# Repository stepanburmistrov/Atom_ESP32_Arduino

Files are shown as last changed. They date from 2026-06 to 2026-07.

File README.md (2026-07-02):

# RobotX UART Wi-Fi Robot

Готовый репозиторий для учебного робота RobotX с двумя режимами управления:

1. **Отладка с компьютера по USB/UART** — Python-пульт отправляет команды прямо в Arduino Nano.
2. **Работа через Wi-Fi модуль ESP32-C3** — телефон/планшет открывает веб-пульт, ESP32 пересылает команды в Arduino Nano по UART.

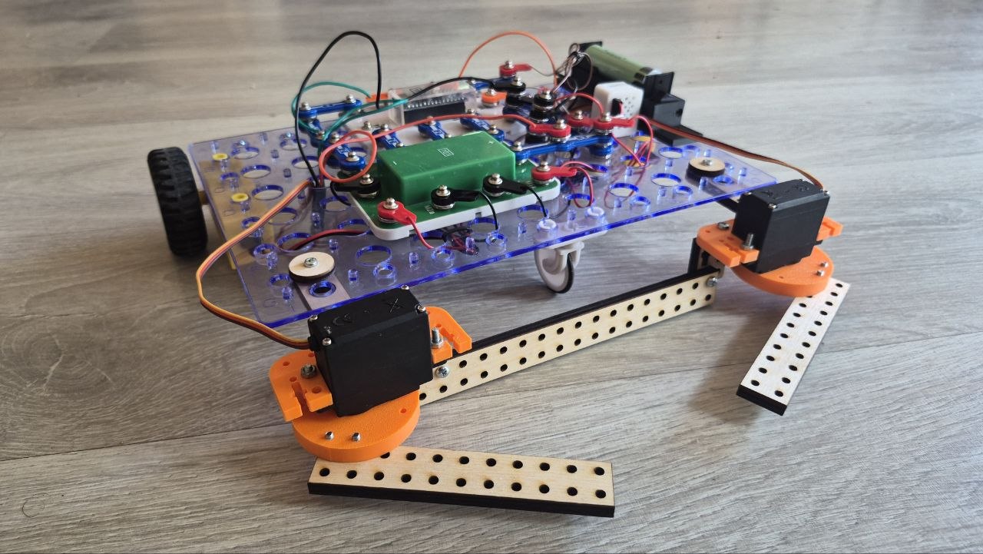
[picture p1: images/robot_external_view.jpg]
Внешний вид робота


## Быстрый старт

### Вариант 1. Отладка с компьютера без ESP32

1. Прошейте Arduino Nano скетчем из папки `arduino/RobotX_Nano_UART_Control/`.
2. Установите Python-зависимость:

```bash
pip install -r pc_control/requirements.txt
```

3. Запустите пульт:

```bash
python pc_control/robotx_uart_control.py
```

4. Выберите COM-порт Arduino Nano, скорость `9600`, нажмите **Подключиться**.

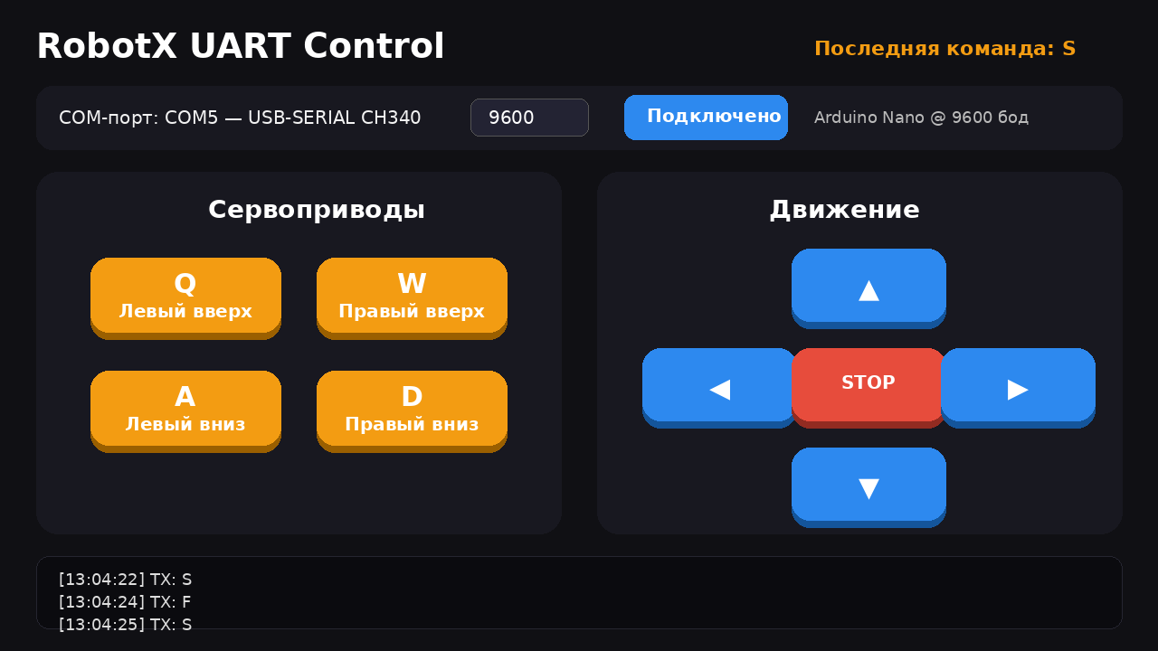
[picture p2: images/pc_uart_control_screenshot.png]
Python UART пульт


### Вариант 2. Управление через ESP32-C3 Wi-Fi

1. Прошейте ESP32-C3 скетчем из папки `esp32_wifi/RobotX_ESP32C3_WiFi_Joystick/`.
2. В Arduino IDE для ESP32-C3 включите: `Tools -> USB CDC On Boot -> Enabled`.
3. Подключите ESP32-C3 к Arduino Nano:

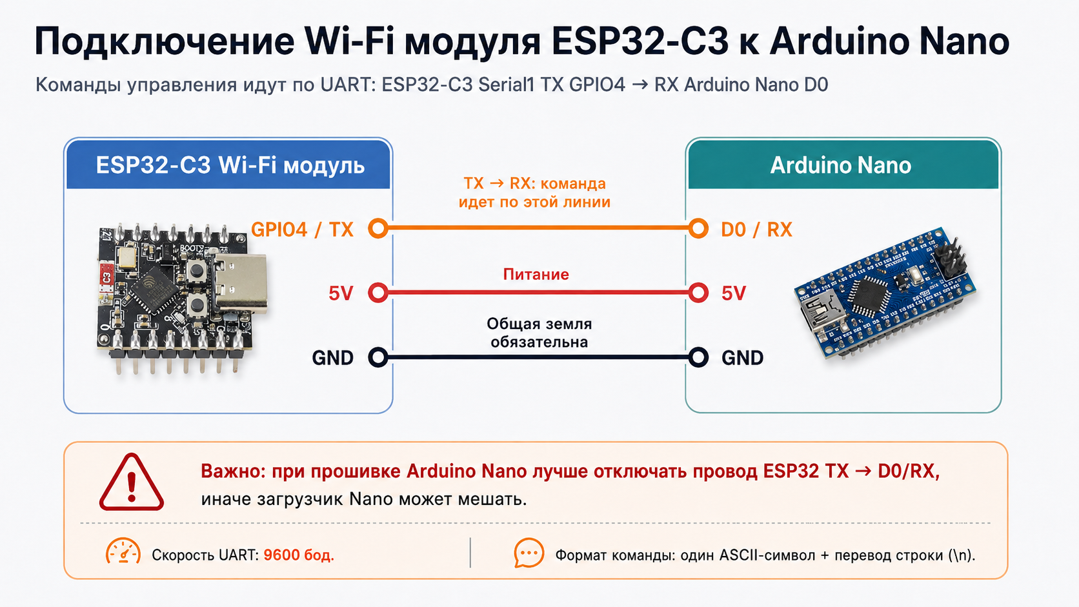
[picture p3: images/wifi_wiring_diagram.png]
Подключение проводов


4. Подключитесь телефоном к Wi-Fi сети ESP32.
5. Откройте в браузере адрес `http://192.168.4.1`.

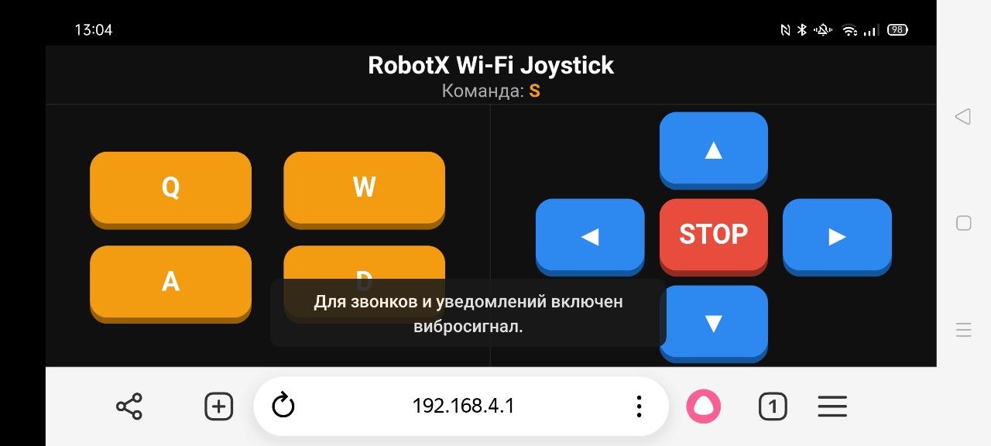
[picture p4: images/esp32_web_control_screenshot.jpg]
ESP32 веб-пульт


## Структура репозитория

```text
RobotX_UART_WiFi_Robot/
├── README.md
├── arduino/
│   ├── RobotX_Nano_UART_Control/
│   │   └── RobotX_Nano_UART_Control.ino
│   └── libraries/
│       └── ServoTimer2-master.zip
├── esp32_wifi/
│   └── RobotX_ESP32C3_WiFi_Joystick/
│       └── RobotX_ESP32C3_WiFi_Joystick.ino
├── pc_control/
│   ├── robotx_uart_control.py
│   └── requirements.txt
├── docs/
│   ├── arduino_project.md
│   ├── wifi_module.md
│   ├── uart_protocol.md
│   └── debug_pc_control.md
├── configs/
│   └── atom_network_presets.txt
├── stl/
│   └── *.stl
└── images/
```

## STL детали для 3D-печати

В папке `stl/` лежат детали для печати:

1. корпус для ESP32-C3;
2. держатели сервоприводов;
3. переходные детали для конструктора «Знаток».

## UART-протокол

Все управляющие команды — это один ASCII-символ и перевод строки `
`.

| Команда | Назначение |
|---|---|
| `F` | ехать вперёд |
| `B` | ехать назад |
| `L` | поворот влево |
| `R` | поворот вправо |
| `S` | стоп моторов |
| `Q` / `q` | левая серва вверх / остановить движение левой сервы вверх |
| `A` / `a` | левая серва вниз / остановить движение левой сервы вниз |
| `W` / `w` | правая серва вверх / остановить движение правой сервы вверх |
| `D` / `d` | правая серва вниз / остановить движение правой сервы вниз |

Подробнее: [`docs/uart_protocol.md`](docs/uart_protocol.md)

## Фотографии проекта

### Внешний вид робота

Внешний вид робота

### Используемые компоненты

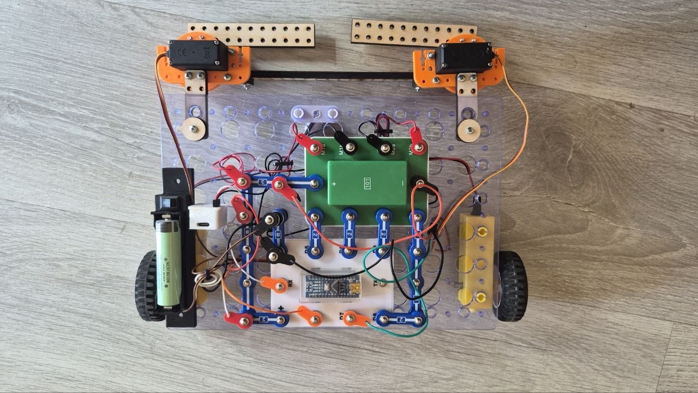
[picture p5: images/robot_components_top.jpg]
Компоненты робота


### Wi-Fi модуль

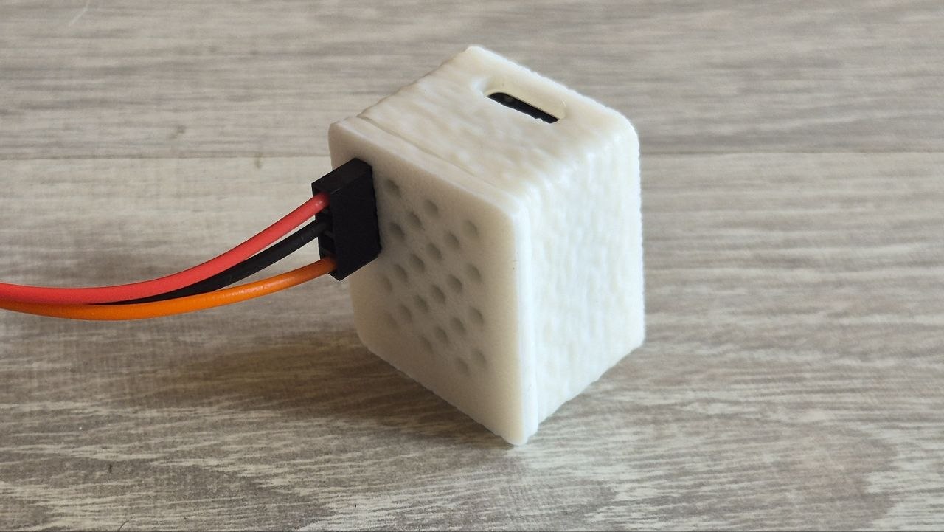
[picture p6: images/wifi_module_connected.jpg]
Wi-Fi модуль


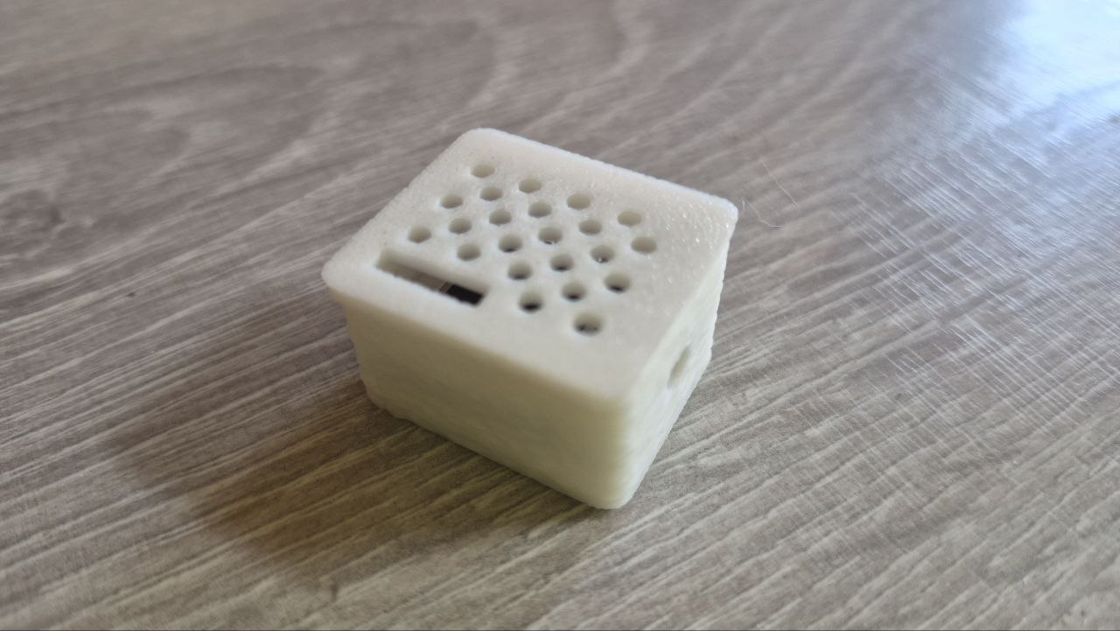
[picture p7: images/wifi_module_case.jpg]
Корпус Wi-Fi модуля


## Важные замечания

- Для работы Python-пульта нужен пакет `pyserial`.
- Для Arduino Nano нужна библиотека `ServoTimer2`; архив библиотеки лежит в `arduino/libraries/`.
- В Arduino-скетче при работе через ESP32 лучше поставить `#define DEBUG_SERIAL 0`, чтобы отладочные сообщения не мешали UART-линии.
- На Arduino Nano пины `D0/RX` и `D1/TX` используются также для загрузки скетча. Если прошивка не загружается, временно отключите провод от ESP32 TX к Nano RX.
- В ESP32-C3 для USB Serial обычно нужно включить `USB CDC On Boot: Enabled`.

## Документация

- [Arduino проект](docs/arduino_project.md)
- [Wi-Fi модуль ESP32-C3](docs/wifi_module.md)
- [UART-протокол](docs/uart_protocol.md)
- [Python-пульт для отладки](docs/debug_pc_control.md)

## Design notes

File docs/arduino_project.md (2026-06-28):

# Arduino Nano проект

Файл скетча: `arduino/RobotX_Nano_UART_Control/RobotX_Nano_UART_Control.ino`

## Что делает Arduino Nano

Arduino Nano является нижним уровнем управления роботом. Он принимает UART-команды и управляет:

- двумя моторами движения;
- двумя сервоприводами клешней/манипуляторов.

Команды могут приходить двумя способами:

1. напрямую с компьютера через USB и Python-пульт;
2. от ESP32-C3 Wi-Fi модуля через UART.

## Основные настройки в коде

### Отладка

```cpp
#define DEBUG_SERIAL 1
```

- `1` — Arduino печатает отладочные сообщения в Serial;
- `0` — отладка отключена.

При прямой отладке с компьютера можно оставить `1`.
При работе через ESP32 лучше поставить `0`, потому что Serial используется для приёма команд, а лишний текст может мешать анализу обмена.

### Скорость UART

```cpp
const int UART_BAUD = 9600;
```

Это скорость связи. Она должна совпадать во всех местах:

- Arduino Nano: `9600`;
- Python-пульт: `9600`;
- ESP32-C3 `Serial1`: `9600`.

### Пины моторов

```cpp
const int LEFT_DIR_PIN  = 5;
const int LEFT_PWM_PIN  = 6;

const int RIGHT_DIR_PIN = 8;
const int RIGHT_PWM_PIN = 9;
```

Что менять:

- `LEFT_DIR_PIN` и `RIGHT_DIR_PIN` — пины направления;
- `LEFT_PWM_PIN` и `RIGHT_PWM_PIN` — пины скорости, должны поддерживать PWM.

### Скорость моторов

```cpp
int motorSpeed = 120;
```

Диапазон: `0...255`.

- меньше значение — робот едет медленнее;
- больше значение — робот едет быстрее;
- для отладки лучше начинать с `80...120`.

### Пины сервоприводов

```cpp
const int LEFT_SERVO_PIN  = A4;
const int RIGHT_SERVO_PIN = 7;
```

Если сервы подключены к другим пинам, менять нужно эти две строки.

### Начальные углы сервоприводов

```cpp
int leftServoAngle  = 90;
int rightServoAngle = 90;
```

Это стартовое положение серв. Если при включении клешни стоят неудобно, можно подобрать другие значения.

### Ограничения углов

```cpp
const int SERVO_MIN_ANGLE = 0;
const int SERVO_MAX_ANGLE = 180;
```

Если механизм упирается раньше полного хода, лучше ограничить диапазон, например:

```cpp
const int SERVO_MIN_ANGLE = 20;
const int SERVO_MAX_ANGLE = 160;
```

### Плавность движения серв

```cpp
const int SERVO_STEP = 1;
const unsigned long SERVO_INTERVAL = 5;
```

- `SERVO_STEP` — насколько градусов менять положение за один шаг;
- `SERVO_INTERVAL` — пауза между шагами в миллисекундах.

Меньше интервал и больше шаг — быстрее движение. Больше интервал и меньше шаг — плавнее движение.

### Отключение серв после отпускания кнопки

```cpp
const unsigned long SERVO_DETACH_DELAY = 200;
```

Через 200 мс после окончания движения серва отключается методом `detach()`.
Это снижает дрожание, писк и лишнее потребление тока.

## Зачем нужна библиотека ServoTimer2

В обычных проектах часто используют стандартную библиотеку:

```cpp
#include <Servo.h>
```

Но на Arduino Nano стандартная `Servo` использует таймер `Timer1`. Из-за этого перестаёт нормально работать PWM на пинах `9` и `10`.

В этом роботе правый мотор использует PWM на пине `9`:

```cpp
const int RIGHT_PWM_PIN = 9;
```

Поэтому стандартная `Servo` конфликтовала бы с управлением мотором.

Решение — использовать:

```cpp
#include <ServoTimer2.h>
```

`ServoTimer2` использует другой таймер и не ломает PWM на 9 пине. Именно поэтому в коде сервоприводы управляются через `ServoTimer2`, а не через стандартную `Servo`.

## Как установить ServoTimer2

1. Возьмите архив `arduino/libraries/ServoTimer2-master.zip`.
2. В Arduino IDE откройте `Sketch -> Include Library -> Add .ZIP Library...`.
3. Выберите этот архив.
4. После установки перезапустите Arduino IDE, если библиотека не подтянулась сразу.

## Логика движения

```cpp
void forward() {
  setLeftMotor(motorSpeed);
  setRightMotor(motorSpeed);
}
```

```cpp
void back() {
  setLeftMotor(-motorSpeed);
  setRightMotor(-motorSpeed);
}
```

```cpp
void turnLeft() {
  setLeftMotor(-motorSpeed);
  setRightMotor(motorSpeed);
}
```

```cpp
void turnRight() {
  setLeftMotor(motorSpeed);
  setRightMotor(-motorSpeed);
}
```

Если робот едет назад вместо вперёд, можно поменять знак у соответствующего мотора или поменять логику в `setLeftMotor()` / `setRightMotor()`.

## Частые проблемы

### Робот не реагирует на команды

Проверьте:

- скорость Serial = `9600`;
- выбран правильный COM-порт;
- команды отправляются с переводом строки `
`;
- при работе через ESP32 есть общий GND между ESP32 и Nano;
- ESP32 TX GPIO4 подключен к Nano RX D0.

### Скетч не загружается в Arduino Nano

Если к пину `D0/RX` подключен ESP32, он может мешать загрузчику Nano. На время прошивки отключите провод `ESP32 TX -> Nano RX`.

### Мотор на 9 пине перестал работать после добавления серв

Нужно использовать `ServoTimer2`, а не стандартную `Servo`. Стандартная библиотека Servo конфликтует с PWM на 9 пине.

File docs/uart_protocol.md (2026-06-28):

# UART-протокол RobotX

## Назначение

UART-протокол нужен, чтобы разные пульты управления могли одинаково управлять Arduino Nano:

- Python-пульт на компьютере отправляет команды через USB Serial Arduino Nano;
- ESP32-C3 получает команды с веб-страницы и пересылает их в Arduino Nano через `Serial1`;
- Arduino Nano не знает, кто именно отправил команду, он просто принимает символы по UART.

## Параметры UART

| Параметр | Значение |
|---|---|
| Скорость | `9600` бод |
| Формат | `SERIAL_8N1` |
| Окончание команды | `
` |
| Кодировка | ASCII |
| Длина полезной команды | 1 символ |

Пример фактической строки:

```text
F

```

## Команды движения

| Команда | Действие Arduino Nano |
|---|---|
| `F` | оба мотора вперёд |
| `B` | оба мотора назад |
| `L` | левый мотор назад, правый вперёд |
| `R` | левый мотор вперёд, правый назад |
| `S` | оба мотора остановлены |

В Python-пульте и веб-пульте команды движения работают как **удерживаемые кнопки**: при нажатии отправляется `F/B/L/R`, при отпускании — `S`.

## Команды сервоприводов

| Команда | Действие |
|---|---|
| `Q` | начать движение левой сервы вверх |
| `q` | остановить движение левой сервы вверх |
| `A` | начать движение левой сервы вниз |
| `a` | остановить движение левой сервы вниз |
| `W` | начать движение правой сервы вверх |
| `w` | остановить движение правой сервы вверх |
| `D` | начать движение правой сервы вниз |
| `d` | остановить движение правой сервы вниз |

Правая серва установлена зеркально, поэтому внутри Arduino-скетча направления `W/D` специально инвертированы.

## Почему команды верхнего и нижнего регистра разные

Для сервоприводов верхний регистр означает **начать движение**, нижний регистр — **остановить соответствующее движение**.

Например:

```text
Q
  левая серва начала двигаться вверх
q
  левая серва остановилась
```

Это удобно для кнопок на экране и клавиатуре: кнопка нажата — серва едет, кнопка отпущена — серва остановилась.

## Проверка без робота

В Arduino IDE можно открыть Serial Monitor на `9600` бод и отправлять команды вручную:

```text
F
S
Q
q
A
a
```

Если включён `DEBUG_SERIAL`, Nano будет печатать диагностические сообщения. При работе с ESP32 лучше отключить отладку:

```cpp
#define DEBUG_SERIAL 0
```

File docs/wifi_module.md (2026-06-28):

# Wi-Fi модуль ESP32-C3

Файл скетча: `esp32_wifi/RobotX_ESP32C3_WiFi_Joystick/RobotX_ESP32C3_WiFi_Joystick.ino`

Wi-Fi модуль с проводами

## Назначение

ESP32-C3 работает как мост:

```text
Телефон / планшет / компьютер
        ↓ Wi-Fi + HTTP
ESP32-C3 WebServer
        ↓ UART Serial1, 9600 бод
Arduino Nano
        ↓
моторы и сервоприводы
```

ESP32 не управляет моторами напрямую. Он только показывает веб-страницу и пересылает команды в Arduino Nano.

## Подключение к Arduino Nano

Подключение проводов

| ESP32-C3 | Arduino Nano | Назначение |
|---|---|---|
| `GPIO4 / TX` | `D0 / RX` | команды от ESP32 к Nano |
| `GPIO5 / RX` | `D1 / TX` | необязательно, обратный канал пока не используется |
| `GND` | `GND` | общая земля, обязательно |

В коде ESP32:

```cpp
const int UART_TX_PIN = 4;
const int UART_RX_PIN = 5;
const int UART_BAUD   = 9600;
```

## Подключение по стандартной точке доступа

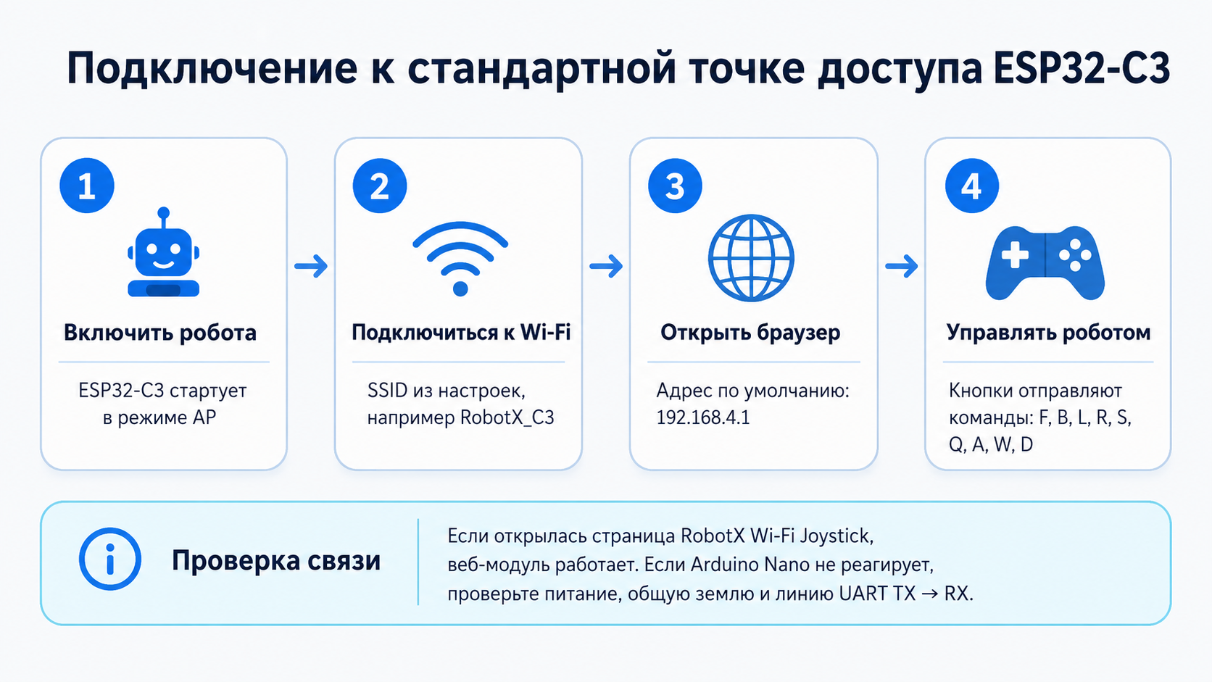
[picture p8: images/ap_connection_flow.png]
Подключение к AP


1. Включить робота.
2. Подключиться телефоном к Wi-Fi сети ESP32.
3. Открыть браузер.
4. Перейти на адрес:

```text
http://192.168.4.1
```

Откроется пульт:

Веб-пульт ESP32

## Веб-адреса

### Главная страница

```text
/
```

Открывает HTML-пульт управления.

### Отправка команды

```text
/cmd?c=F
```

Параметр `c` — команда. Примеры:

```text
/cmd?c=F  вперёд
/cmd?c=S  стоп
/cmd?c=Q  левая серва вверх
/cmd?c=q  остановить движение левой сервы вверх
```

### Информация о модуле

```text
/info
```

Возвращает текстовую информацию:

- режим Wi-Fi;
- имя AP;
- STA SSID;
- текущий IP;
- UART TX/RX;
- скорость UART.

## USB Serial для настройки

Настройка ESP32 выполняется через USB Serial на скорости `115200` бод.

Для ESP32-C3 в Arduino IDE обычно нужно включить:

```text
Tools -> USB CDC On Boot -> Enabled
```

После прошивки откройте Serial Monitor:

```text
115200 baud
Newline или Both NL & CR
```

## Команды настройки

### HELP

```text
HELP
```

Печатает список доступных команд.

### INFO

```text
INFO
```

Показывает текущие настройки:

- режим `AP` или `STA`;
- AP SSID и пароль;
- STA SSID и пароль;
- статический IP включён или нет;
- текущий IP.

### SETMODE AP

```text
SETMODE AP
```

Сохраняет режим точки доступа. После команды нужно выполнить:

```text
REBOOT
```

### SETMODE STA

```text
SETMODE STA
```

Сохраняет режим подключения к существующей Wi-Fi сети. После команды нужно задать сеть командой `SETSTA`, а затем выполнить `REBOOT`.

### SETAP

```text
SETAP Atom_BAL 55551111
```

Задаёт имя и пароль точки доступа ESP32.

Формат:

```text
SETAP <SSID> <PASSWORD>
```

Требования:

- пароль AP должен быть не короче 8 символов;
- SSID и пароль лучше писать без пробелов.

### SETSTA

```text
SETSTA MyWiFi mypassword
```

Задаёт сеть, к которой ESP32 будет подключаться в режиме `STA`.

Формат:

```text
SETSTA <SSID> <PASSWORD>
```

### SETDHCP

```text
SETDHCP
```

Отключает статический IP. В режиме `STA` адрес будет выдаваться роутером.

### SETSTATIC

```text
SETSTATIC 192.168.1.77 192.168.1.1 255.255.255.0 8.8.8.8
```

Формат:

```text
SETSTATIC <IP> <GATEWAY> <SUBNET> <DNS>
```

В репозиторной версии скетча статический IP не только сохраняется в NVS, но и применяется перед `WiFi.begin()` через `WiFi.config(...)`.

### REBOOT

```text
REBOOT
```

Перезагружает ESP32. Нужен после изменения режима или Wi-Fi настроек.

## Пример настройки точки доступа

```text
SETAP Atom_BAL 55551111
SETMODE AP
REBOOT
```

После перезагрузки подключиться к сети `Atom_BAL` с паролем `55551111` и открыть:

```text
http://192.168.4.1
```

## Пример настройки подключения к роутеру

```text
SETSTA MyWiFi mypassword
SETMODE STA
SETDHCP
REBOOT
```

После перезагрузки ESP32 подключится к роутеру. Текущий IP можно посмотреть командой `INFO` через USB Serial или в интерфейсе роутера.

## Что проверено в коде

- Веб-страница отправляет `/cmd?c=...`.
- Обработчик `/cmd` вызывает `sendToNano(cmd)`.
- `sendToNano()` отправляет команду в `Serial1` и добавляет `
`.
- `Serial1` настроен как `9600, SERIAL_8N1, RX=GPIO5, TX=GPIO4`.
- Настройки Wi-Fi сохраняются в `Preferences` / NVS.
- Для режима `STA` добавлено применение статического IP через `WiFi.config(...)`.

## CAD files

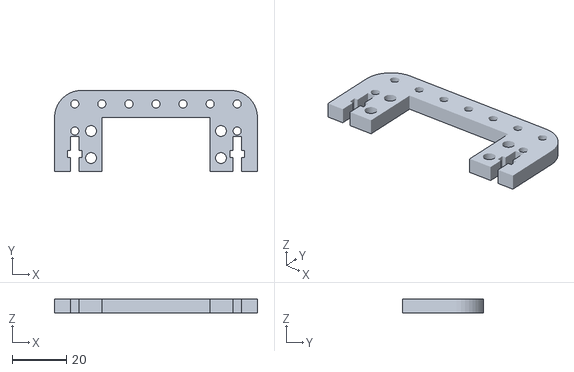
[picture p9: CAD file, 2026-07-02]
STL/Скоба крепления сервопривода.STL
75.0 x 30.0 x 5.00

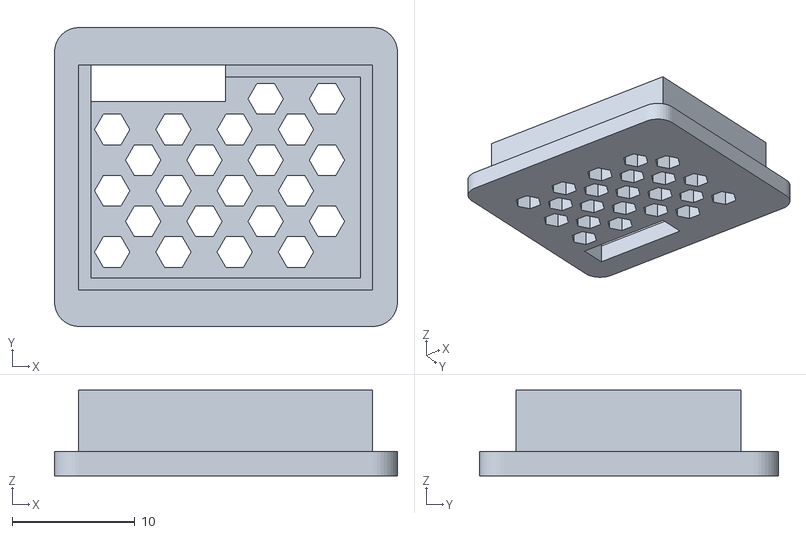
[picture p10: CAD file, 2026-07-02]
STL/Крышка корпуса ESP.STL
28.0 x 24.4 x 7.00

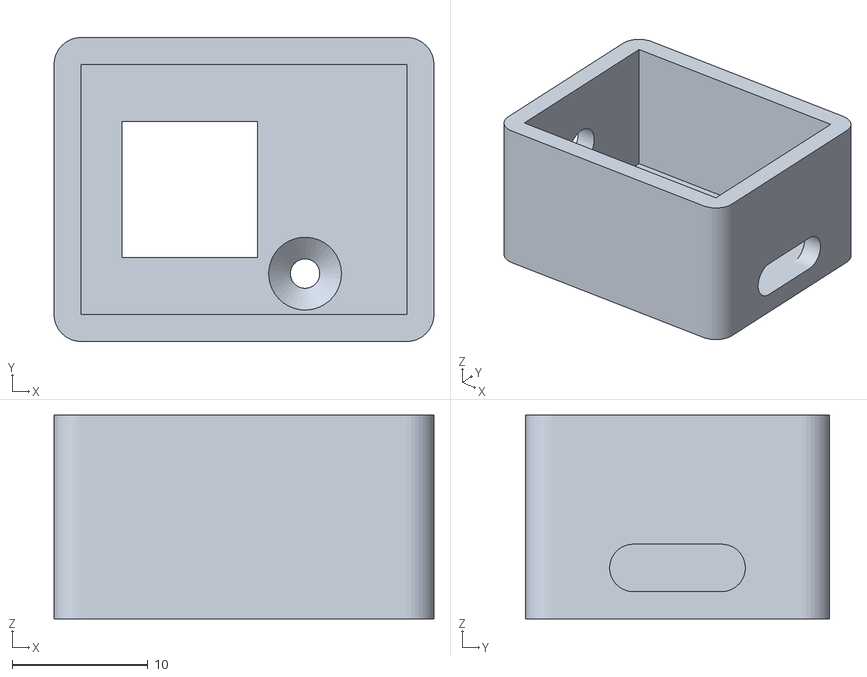
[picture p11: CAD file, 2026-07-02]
STL/Корпус ESP.STL
28.0 x 22.4 x 15.0

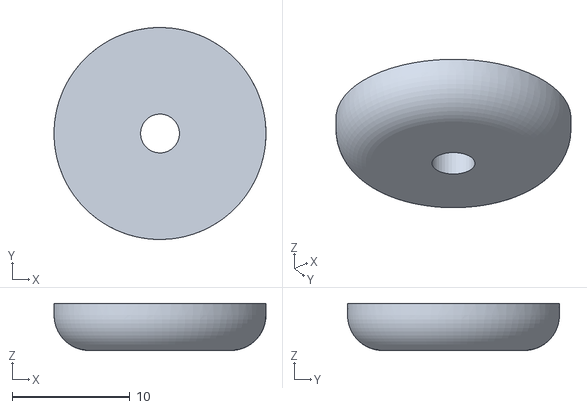
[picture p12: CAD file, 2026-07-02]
STL/Шайба.STL
18.0 x 18.0 x 4.00

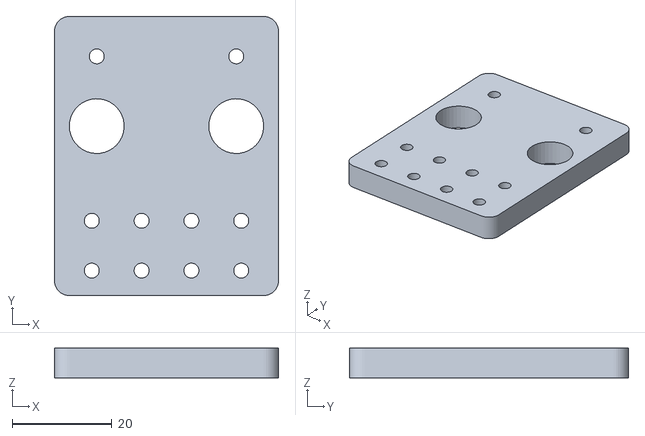
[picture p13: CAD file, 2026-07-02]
STL/Деталь 01.STL
45.0 x 56.0 x 6.00

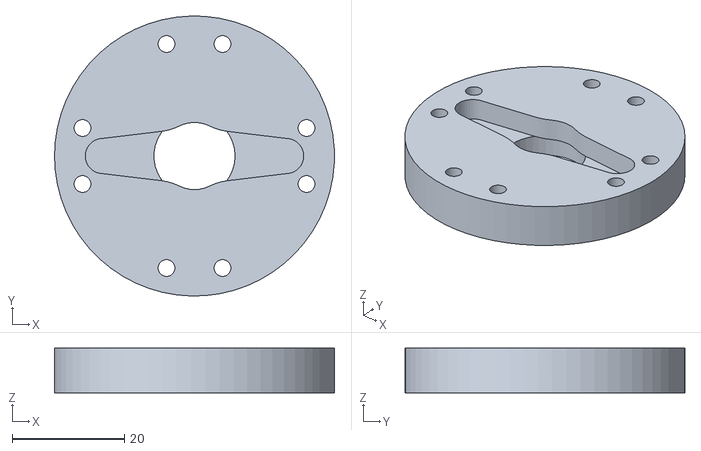
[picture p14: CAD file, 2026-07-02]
STL/КругПечать.STL
50.0 x 50.0 x 8.00

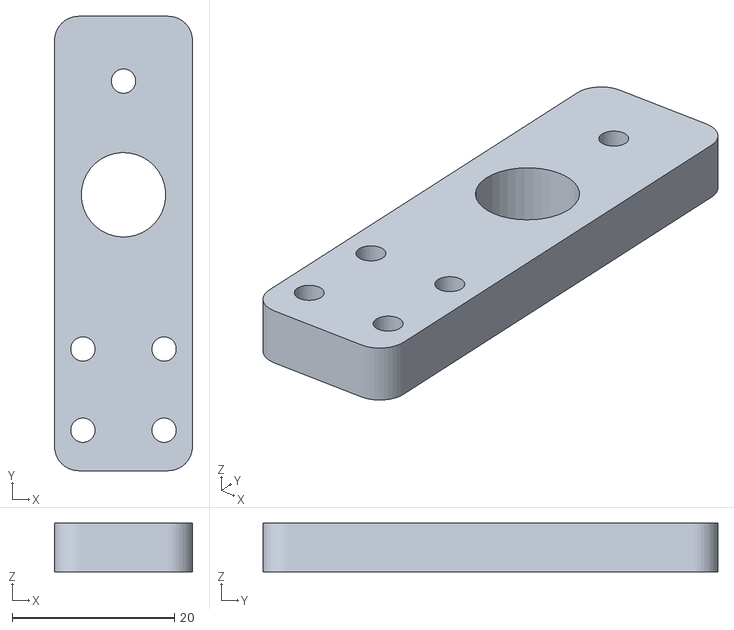
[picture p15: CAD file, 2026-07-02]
STL/Деталь 01-1.STL
17.0 x 56.0 x 6.00

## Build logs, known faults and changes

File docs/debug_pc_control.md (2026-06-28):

# Python-пульт для отладки с компьютера

Файл: `pc_control/robotx_uart_control.py`

Python UART пульт

## Зачем нужен

Этот пульт нужен, чтобы отлаживать Arduino Nano и механику робота **до подключения ESP32**.

Схема работы:

```text
Компьютер
  ↓ USB кабель
Arduino Nano
  ↓
моторы и сервоприводы
```

Python отправляет в Arduino Nano те же команды, которые позже будет отправлять ESP32.

## Установка

В папке репозитория выполнить:

```bash
pip install -r pc_control/requirements.txt
```

## Запуск

```bash
python pc_control/robotx_uart_control.py
```

## Управление мышью

Кнопки на экране работают как удерживаемые:

- нажали кнопку — команда отправилась;
- отпустили кнопку — отправилась команда остановки.

Для движения при отпускании отправляется `S`.
Для сервоприводов при отпускании отправляется соответствующая маленькая буква: `q`, `a`, `w`, `d`.

## Управление клавиатурой

| Клавиша | Команда |
|---|---|
| `↑` | `F` — вперёд |
| `↓` | `B` — назад |
| `←` | `L` — влево |
| `→` | `R` — вправо |
| `Space` | `S` — стоп |
| `Q` | `Q/q` — левая серва вверх / стоп |
| `A` | `A/a` — левая серва вниз / стоп |
| `W` | `W/w` — правая серва вверх / стоп |
| `D` | `D/d` — правая серва вниз / стоп |

Для моторов специально используются стрелки, чтобы не конфликтовать с командами сервоприводов `Q/W/A/D`.

## Настройки

По умолчанию скорость:

```text
9600 бод
```

Она должна совпадать с Arduino:

```cpp
const int UART_BAUD = 9600;
```

## Режим DEMO

Если COM-порт не подключён, кнопки всё равно будут писать команды в лог как `DEMO TX`. Это удобно, чтобы проверить интерфейс без робота.

## Частые проблемы

### COM-порт не появился

Проверьте:

- подключён ли USB кабель;
- установлен ли драйвер CH340/FTDI;
- не открыт ли этот порт в Arduino IDE Serial Monitor.

### Arduino перезагружается при подключении

Это нормально: многие платы Nano перезапускаются при открытии Serial-порта. В программе после подключения есть небольшая пауза, чтобы плата успела стартовать.

### Робот не реагирует

Проверьте:

- выбран правильный COM-порт;
- скорость 9600;
- Arduino прошит скетчем `RobotX_Nano_UART_Control.ino`;
- в Arduino IDE закрыт Serial Monitor, иначе порт может быть занят.

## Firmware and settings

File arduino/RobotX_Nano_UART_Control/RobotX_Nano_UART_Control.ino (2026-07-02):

/*
  RobotX Nano UART Control
  ------------------------
  Управляет двумя моторами и двумя сервоприводами по UART-командам.
  Команды приходят по Serial на скорости 9600 бод: от Python-пульта через USB
  или от ESP32-C3 Wi-Fi модуля через GPIO4 -> RX Arduino Nano.

  Подробнее: см. docs/arduino_project.md и docs/uart_protocol.md
*/

#include <ServoTimer2.h>

// =====================
// ОТЛАДКА
// 1 — включить отладку в Serial
// 0 — выключить отладку
// ВАЖНО: при работе с ESP32 лучше ставить 0,
// потому что команды тоже приходят в RX Serial.
// =====================

#define DEBUG_SERIAL 1

#if DEBUG_SERIAL
  #define DBG_BEGIN(x) Serial.begin(x)
  #define DBG_PRINT(x) Serial.print(x)
  #define DBG_PRINTLN(x) Serial.println(x)
#else
  #define DBG_BEGIN(x)
  #define DBG_PRINT(x)
  #define DBG_PRINTLN(x)
#endif

// =====================
// UART ОТ ESP32
// =====================

const int UART_BAUD = 9600;

// =====================
// МОТОРЫ
// =====================

const int LEFT_DIR_PIN  = 5;
const int LEFT_PWM_PIN  = 6;

const int RIGHT_DIR_PIN = 8;
const int RIGHT_PWM_PIN = 9;

int motorSpeed = 160;

// =====================
// СЕРВЫ
// =====================

ServoTimer2 leftServo;
ServoTimer2 rightServo;

const int LEFT_SERVO_PIN  = A4;
const int RIGHT_SERVO_PIN = 7;

int leftServoAngle  = 90;
int rightServoAngle = 90;

const int SERVO_MIN_ANGLE = 0;
const int SERVO_MAX_ANGLE = 180;

const int SERVO_STEP = 1;
const unsigned long SERVO_INTERVAL = 5;

// Через сколько мс после окончания движения отключать серву
const unsigned long SERVO_DETACH_DELAY = 200;

unsigned long lastServoTime = 0;

bool leftServoAttached = false;
bool rightServoAttached = false;

unsigned long leftServoLastActiveTime = 0;
unsigned long rightServoLastActiveTime = 0;

// =====================
// СОСТОЯНИЕ СЕРВО
// =====================

bool leftServoUp     = false;
bool leftServoDown   = false;
bool rightServoUp    = false;
bool rightServoDown  = false;

// =====================
// ОТЛАДОЧНЫЙ ТАЙМЕР
// =====================

#if DEBUG_SERIAL
unsigned long lastDebugTime = 0;
const unsigned long DEBUG_INTERVAL = 500;
#endif

// =====================
// СЕРВО TIMER2
// =====================

int angleToPulse(int angle) {
  angle = constrain(angle, 0, 180);
  return map(angle, 0, 180, 750, 2250);
}

void writeServoAngle(ServoTimer2 &s, int angle) {
  s.write(angleToPulse(angle));
}

void attachLeftServoIfNeeded() {
  if (!leftServoAttached) {
    leftServo.attach(LEFT_SERVO_PIN);
    leftServoAttached = true;

    // Сразу записываем текущий угол,
    // чтобы серва не дернулась в случайное положение
    writeServoAngle(leftServo, leftServoAngle);

    DBG_PRINTLN("LEFT SERVO ATTACH");
  }

  leftServoLastActiveTime = millis();
}

void attachRightServoIfNeeded() {
  if (!rightServoAttached) {
    rightServo.attach(RIGHT_SERVO_PIN);
    rightServoAttached = true;

    // Сразу записываем текущий угол,
    // чтобы серва не дернулась в случайное положение
    writeServoAngle(rightServo, rightServoAngle);

    DBG_PRINTLN("RIGHT SERVO ATTACH");
  }

  rightServoLastActiveTime = millis();
}

void detachServosIfNeeded() {
  unsigned long now = millis();

  bool leftMoving = leftServoUp || leftServoDown;
  bool rightMoving = rightServoUp || rightServoDown;

  if (leftServoAttached && !leftMoving) {
    if (now - leftServoLastActiveTime >= SERVO_DETACH_DELAY) {
      leftServo.detach();
      leftServoAttached = false;

      DBG_PRINTLN("LEFT SERVO DETACH");
    }
  }

  if (rightServoAttached && !rightMoving) {
    if (now - rightServoLastActiveTime >= SERVO_DETACH_DELAY) {
      rightServo.detach();
      rightServoAttached = false;

      DBG_PRINTLN("RIGHT SERVO DETACH");
    }
  }
}

// =====================
// SETUP
// =====================

void setup() {
  Serial.begin(UART_BAUD);
  Serial.setTimeout(10);

  DBG_PRINTLN("================================");
  DBG_PRINTLN("RobotX Arduino Nano UART control");
  DBG_PRINTLN("RX commands from ESP32");
  DBG_PRINTLN("================================");

  pinMode(LEFT_DIR_PIN, OUTPUT);
  pinMode(LEFT_PWM_PIN, OUTPUT);

  pinMode(RIGHT_DIR_PIN, OUTPUT);
  pinMode(RIGHT_PWM_PIN, OUTPUT);

  // ВАЖНО:
  // Сервы НЕ подключаем постоянно.
  // Они подключатся только при команде движения.
  leftServoAttached = false;
  rightServoAttached = false;

  stopMotors();
  stopServoButtons();

  DBG_PRINTLN("Setup complete");
}

// =====================
// LOOP
// =====================

void loop() {
  readUartCommands();
  updateServos();
  debugState();
}

// =====================
// ПРИЁМ UART ОТ ESP32
// =====================

void readUartCommands() {
  while (Serial.available()) {
    String cmdLine = Serial.readStringUntil('\n');
    cmdLine.trim();

    if (cmdLine.length() == 0) return;

    char cmd = cmdLine.charAt(0);

    DBG_PRINT("RX: ");
    DBG_PRINTLN(cmd);

    handleCommand(cmd);
  }
}

// =====================
// КОМАНДЫ ОТ ESP32
//
// F — вперед
// B — назад
// L — влево
// R — вправо
// S — стоп
//
// Q/q — левая серва вверх / стоп
// A/a — левая серва вниз / стоп
// W/w — правая серва вверх / стоп
// D/d — правая серва вниз / стоп
//
// ВАЖНО:
// Правая серва стоит зеркально,
// поэтому W/D специально включают обратные направления.
// =====================

void handleCommand(char cmd) {
  switch (cmd) {
    case 'F':
      DBG_PRINTLN("CMD: FORWARD");
      forward();
      break;

    case 'B':
      DBG_PRINTLN("CMD: BACK");
      back();
      break;

    case 'L':
      DBG_PRINTLN("CMD: LEFT");
      turnLeft();
      break;

    case 'R':
      DBG_PRINTLN("CMD: RIGHT");
      turnRight();
      break;

    case 'S':
      DBG_PRINTLN("CMD: STOP MOTORS");
      stopMotors();
      break;

    case 'Q':
      DBG_PRINTLN("CMD: LEFT SERVO UP START");
      attachLeftServoIfNeeded();
      leftServoUp = true;
      leftServoDown = false;
      break;

    case 'q':
      DBG_PRINTLN("CMD: LEFT SERVO UP STOP");
      leftServoUp = false;
      leftServoLastActiveTime = millis();
      break;

    case 'A':
      DBG_PRINTLN("CMD: LEFT SERVO DOWN START");
      attachLeftServoIfNeeded();
      leftServoDown = true;
      leftServoUp = false;
      break;

    case 'a':
      DBG_PRINTLN("CMD: LEFT SERVO DOWN STOP");
      leftServoDown = false;
      leftServoLastActiveTime = millis();
      break;

    case 'W':
      DBG_PRINTLN("CMD: RIGHT SERVO UP START MIRRORED");
      attachRightServoIfNeeded();

      // Правая серва стоит зеркально,
      // поэтому команда W включает rightServoDown
      rightServoDown = true;
      rightServoUp = false;
      break;

    case 'w':
      DBG_PRINTLN("CMD: RIGHT SERVO UP STOP MIRRORED");
      rightServoDown = false;
      rightServoLastActiveTime = millis();
      break;

    case 'D':
      DBG_PRINTLN("CMD: RIGHT SERVO DOWN START MIRRORED");
      attachRightServoIfNeeded();

      // Правая серва стоит зеркально,
      // поэтому команда D включает rightServoUp
      rightServoUp = true;
      rightServoDown = false;
      break;

    case 'd':
      DBG_PRINTLN("CMD: RIGHT SERVO DOWN STOP MIRRORED");
      rightServoUp = false;
      rightServoLastActiveTime = millis();
      break;

    default:
      DBG_PRINT("UNKNOWN CMD: ");
      DBG_PRINTLN(cmd);
      break;
  }
}

// =====================
// МОТОРЫ
// =====================

void setLeftMotor(int speed) {
  speed = constrain(speed, -255, 255);

  if (speed > 0) {
    digitalWrite(LEFT_DIR_PIN, LOW);
    analogWrite(LEFT_PWM_PIN, speed);
  } 
  else if (speed < 0) {
    digitalWrite(LEFT_DIR_PIN, HIGH);
    analogWrite(LEFT_PWM_PIN, 255+speed);
  } 
  else {
    digitalWrite(LEFT_DIR_PIN, LOW);
    analogWrite(LEFT_PWM_PIN, 0);
  }
}

void setRightMotor(int speed) {
  speed = constrain(speed, -255, 255);

  if (speed > 0) {
    digitalWrite(RIGHT_DIR_PIN, LOW);
    analogWrite(RIGHT_PWM_PIN, speed);
  } 
  else if (speed < 0) {
    digitalWrite(RIGHT_DIR_PIN, HIGH);
    analogWrite(RIGHT_PWM_PIN, 255+speed);
  } 
  else {
    digitalWrite(RIGHT_DIR_PIN, LOW);
    analogWrite(RIGHT_PWM_PIN, 0);
  }
}

void forward() {
  setLeftMotor(motorSpeed);
  setRightMotor(motorSpeed);
}

void back() {
  setLeftMotor(-motorSpeed);
  setRightMotor(-motorSpeed);
}

void turnLeft() {
  setLeftMotor(-motorSpeed);
  setRightMotor(motorSpeed);
}

void turnRight() {
  setLeftMotor(motorSpeed);
  setRightMotor(-motorSpeed);
}

void stopMotors() {
  setLeftMotor(0);
  setRightMotor(0);
}

// =====================
// СЕРВЫ
// =====================

void stopServoButtons() {
  leftServoUp = false;
  leftServoDown = false;
  rightServoUp = false;
  rightServoDown = false;

  leftServoLastActiveTime = millis();
  rightServoLastActiveTime = millis();
}

void updateServos() {
  unsigned long now = millis();

  // Даже если ещё не пора двигать сервы,
  // всё равно проверяем, не пора ли отключить их
  if (now - lastServoTime < SERVO_INTERVAL) {
    detachServosIfNeeded();
    return;
  }

  lastServoTime = now;

  bool changedLeft = false;
  bool changedRight = false;

  bool leftMoving = leftServoUp || leftServoDown;
  bool rightMoving = rightServoUp || rightServoDown;

  // ---------- Левая серва ----------
  if (leftMoving) {
    attachLeftServoIfNeeded();

    if (leftServoUp) {
      leftServoAngle -= SERVO_STEP;
      changedLeft = true;
    }

    if (leftServoDown) {
      leftServoAngle += SERVO_STEP;
      changedLeft = true;
    }

    leftServoAngle = constrain(leftServoAngle, SERVO_MIN_ANGLE, SERVO_MAX_ANGLE);

    if (changedLeft) {
      writeServoAngle(leftServo, leftServoAngle);
    }

    leftServoLastActiveTime = now;
  }

  // ---------- Правая серва ----------
  if (rightMoving) {
    attachRightServoIfNeeded();

    if (rightServoUp) {
      rightServoAngle -= SERVO_STEP;
      changedRight = true;
    }

    if (rightServoDown) {
      rightServoAngle += SERVO_STEP;
      changedRight = true;
    }

    rightServoAngle = constrain(rightServoAngle, SERVO_MIN_ANGLE, SERVO_MAX_ANGLE);

    if (changedRight) {
      writeServoAngle(rightServo, rightServoAngle);
    }

    rightServoLastActiveTime = now;
  }

  detachServosIfNeeded();
}

// =====================
// ОТЛАДКА СОСТОЯНИЯ
// =====================

void debugState() {
#if DEBUG_SERIAL
  if (millis() - lastDebugTime < DEBUG_INTERVAL) return;
  lastDebugTime = millis();

  DBG_PRINT("LeftServo=");
  DBG_PRINT(leftServoAngle);

  DBG_PRINT(" RightServo=");
  DBG_PRINT(rightServoAngle);

  DBG_PRINT(" | L_UP=");
  DBG_PRINT(leftServoUp);

  DBG_PRINT(" L_DOWN=");
  DBG_PRINT(leftServoDown);

  DBG_PRINT(" R_UP=");
  DBG_PRINT(rightServoUp);

  DBG_PRINT(" R_DOWN=");
  DBG_PRINT(rightServoDown);

  DBG_PRINT(" | L_ATT=");
  DBG_PRINT(leftServoAttached);

  DBG_PRINT(" R_ATT=");
  DBG_PRINTLN(rightServoAttached);
#endif
}

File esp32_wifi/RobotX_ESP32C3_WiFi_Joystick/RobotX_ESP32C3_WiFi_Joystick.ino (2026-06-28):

/*
  RobotX ESP32-C3 Wi-Fi UART Joystick
  -----------------------------------
  Создаёт веб-пульт управления и пересылает команды на Arduino Nano по UART.
  USB Serial на 115200 бод используется для настройки AP/STA и параметров сети.

  Важно для Arduino IDE / ESP32-C3:
  Tools -> USB CDC On Boot -> Enabled

  Подробнее: docs/wifi_module.md и docs/uart_protocol.md
*/

#include <Arduino.h>
#include <WiFi.h>
#include <WebServer.h>
#include <Preferences.h>

// =====================
// UART К ARDUINO NANO
// =====================
const int UART_TX_PIN = 4;   // ESP32-C3 TX -> Arduino Nano RX
const int UART_RX_PIN = 5;   // можно не подключать
const int UART_BAUD   = 9600;

// =====================
// WIFI / WEB
// =====================
Preferences prefs;
WebServer server(80);

String wifiMode = "AP";  // AP или STA

String apName = "Kod_atoma_01";
String apPass = "12345678";

String staSsid = "";
String staPass = "";

bool useStaticIp = false;
String staticIp   = "192.168.1.77";
String gatewayIp  = "192.168.1.1";
String subnetMask = "255.255.255.0";
String dnsIp      = "8.8.8.8";

// =====================
// HTML СТРАНИЦА
// =====================
const char MAIN_page[] PROGMEM = R"rawliteral(
<!DOCTYPE html>
<html lang="ru">
<head>
<meta charset="UTF-8">
<title>RobotX Wi-Fi Joystick</title>
<meta name="viewport" content="width=device-width, initial-scale=1.0, user-scalable=no">
<style>
* {
  box-sizing: border-box;
  -webkit-tap-highlight-color: transparent;
}

html, body {
  margin: 0;
  padding: 0;
  width: 100%;
  height: 100%;
  overflow: hidden;
  background: #101010;
  color: white;
  font-family: Arial, sans-serif;
  touch-action: none;
  user-select: none;
}

body {
  display: flex;
  flex-direction: column;
}

.header {
  height: 72px;
  min-height: 72px;
  text-align: center;
  border-bottom: 1px solid #222;
}

h1 {
  margin: 12px 0 4px 0;
  font-size: 28px;
}

.status {
  font-size: 20px;
  color: #aaa;
}

.status span {
  color: #f39c12;
  font-weight: bold;
}

.main {
  flex: 1;
  display: flex;
  width: 100%;
  min-height: 0;
}

.panel {
  width: 50%;
  height: 100%;
  padding: 10px 32px 14px 32px;
  display: flex;
  flex-direction: column;
  justify-content: center;
}

.leftPanel {
  border-right: 1px solid #252525;
}

.panelTitle {
  text-align: center;
  font-size: 24px;
  font-weight: bold;
  margin-bottom: 14px;
}

.servoGrid {
  display: grid;
  grid-template-columns: 1fr 1fr;
  gap: 22px 28px;
}

.driveGrid {
  width: 100%;
  max-width: 520px;
  margin: 0 auto;
  display: grid;
  grid-template-columns: 1fr 1fr 1fr;
  gap: 16px;
  align-items: center;
}

.btn {
  height: 92px;
  border: none;
  border-radius: 20px;
  color: white;
  font-weight: bold;
  font-size: 30px;
  background: #2d89ef;
  box-shadow: 0 7px #14559b;
}

.btn:active {
  transform: translateY(5px);
  box-shadow: 0 2px #14559b;
  filter: brightness(0.9);
}

.servo {
  background: #f39c12;
  box-shadow: 0 7px #9a5f00;
}

.stop {
  background: #e74c3c;
  box-shadow: 0 7px #922b21;
}

.empty {
  visibility: hidden;
}

.smallText {
  display: block;
  margin-top: 6px;
  font-size: 14px;
  font-weight: normal;
  opacity: 0.9;
}

.footer {
  height: 42px;
  min-height: 42px;
  text-align: center;
  color: #999;
  font-size: 15px;
  border-top: 1px solid #222;
  padding-top: 4px;
}

@media (orientation: portrait) {
  .main {
    flex-direction: column;
  }

  .panel {
    width: 100%;
    height: 50%;
    padding: 8px 18px;
  }

  .leftPanel {
    border-right: none;
    border-bottom: 1px solid #252525;
  }

  .header {
    height: 66px;
    min-height: 66px;
  }

  h1 {
    font-size: 22px;
    margin-top: 8px;
  }

  .panelTitle {
    font-size: 19px;
    margin-bottom: 8px;
  }

  .btn {
    height: 62px;
    font-size: 24px;
    border-radius: 14px;
  }

  .smallText {
    display: none;
  }

  .footer {
    display: none;
  }
}

@media (max-height: 430px) and (orientation: landscape) {
  .header {
    height: 56px;
    min-height: 56px;
  }

  h1 {
    font-size: 24px;
    margin: 6px 0 2px 0;
  }

  .status {
    font-size: 17px;
  }

  .panel {
    padding: 6px 36px 8px 36px;
  }

  .panelTitle {
    font-size: 21px;
    margin-bottom: 8px;
  }

  .btn {
    height: 70px;
    font-size: 25px;
    border-radius: 17px;
    box-shadow: 0 5px #14559b;
  }

  .servo {
    box-shadow: 0 5px #9a5f00;
  }

  .stop {
    box-shadow: 0 5px #922b21;
  }

  .servoGrid {
    gap: 18px 26px;
  }

  .driveGrid {
    max-width: 470px;
    gap: 12px;
  }

  .smallText {
    font-size: 12px;
    margin-top: 3px;
  }

  .footer {
    height: 28px;
    min-height: 28px;
    font-size: 13px;
    padding-top: 2px;
  }
}

@media (max-height: 360px) and (orientation: landscape) {
  .header {
    height: 48px;
    min-height: 48px;
  }

  h1 {
    font-size: 20px;
    margin: 4px 0 0 0;
  }

  .status {
    font-size: 15px;
  }

  .panelTitle {
    display: none;
  }

  .btn {
    height: 58px;
    font-size: 22px;
    border-radius: 14px;
  }

  .smallText {
    display: none;
  }

  .footer {
    display: none;
  }
}
</style>
</head>

<body>

<div class="header">
  <h1>RobotX Wi-Fi Joystick</h1>
  <div class="status">Команда: <span id="status">S</span></div>
</div>

<div class="main">

  <div class="panel leftPanel">
    <div class="panelTitle">Сервоприводы</div>
    <div class="servoGrid">
      <button class="btn servo" data-cmd="Q">
        Q
        <span class="smallText">Левый вверх</span>
      </button>

      <button class="btn servo" data-cmd="W">
        W
        <span class="smallText">Правый вверх</span>
      </button>

      <button class="btn servo" data-cmd="A">
        A
        <span class="smallText">Левый вниз</span>
      </button>

      <button class="btn servo" data-cmd="D">
        D
        <span class="smallText">Правый вниз</span>
      </button>
    </div>
  </div>

  <div class="panel rightPanel">
    <div class="panelTitle">Движение</div>
    <div class="driveGrid">
      <div class="empty"></div>

      <button class="btn" data-cmd="F">
        ▲
        <span class="smallText">ВПЕРЕД</span>
      </button>

      <div class="empty"></div>

      <button class="btn" data-cmd="L">
        ◀
        <span class="smallText">ВЛЕВО</span>
      </button>

      <button class="btn stop" data-cmd="S">
        STOP
        <span class="smallText">СТОП</span>
      </button>

      <button class="btn" data-cmd="R">
        ▶
        <span class="smallText">ВПРАВО</span>
      </button>

      <div class="empty"></div>

      <button class="btn" data-cmd="B">
        ▼
        <span class="smallText">НАЗАД</span>
      </button>

      <div class="empty"></div>
    </div>
  </div>

</div>

<div class="footer">
  Движение: F/B/L/R, стоп: S. Сервы: Q/q, A/a, W/w, D/d
</div>

<script>
let lastCmd = "";
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
